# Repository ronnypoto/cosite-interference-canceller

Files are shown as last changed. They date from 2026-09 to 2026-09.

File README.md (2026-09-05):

# Active Wideband Co-Site Interference Cancellation System

**Tactical VHF, 30–88 MHz** · Final year project, B.Sc. Electrical Engineering
Afeka Tel Aviv Academic College of Engineering

**Ronny Pustilnik · Adir Lemair** — Advisor: Tzvika Rosenblum

---

## What this is

A real-time active canceller for co-site interference: the problem where a
high-power transmitter sitting next to a receiver saturates its input stages
and blinds it completely.

The system taps a reference copy of the interferer, multiplies it by two
adaptive weights (I and Q) in an analog vector modulator to synthesise an
anti-phase replica, and subtracts that replica in a 180° combiner. An STM32
closes the loop at 30 kHz using a logarithmic RF power detector as its only
feedback.

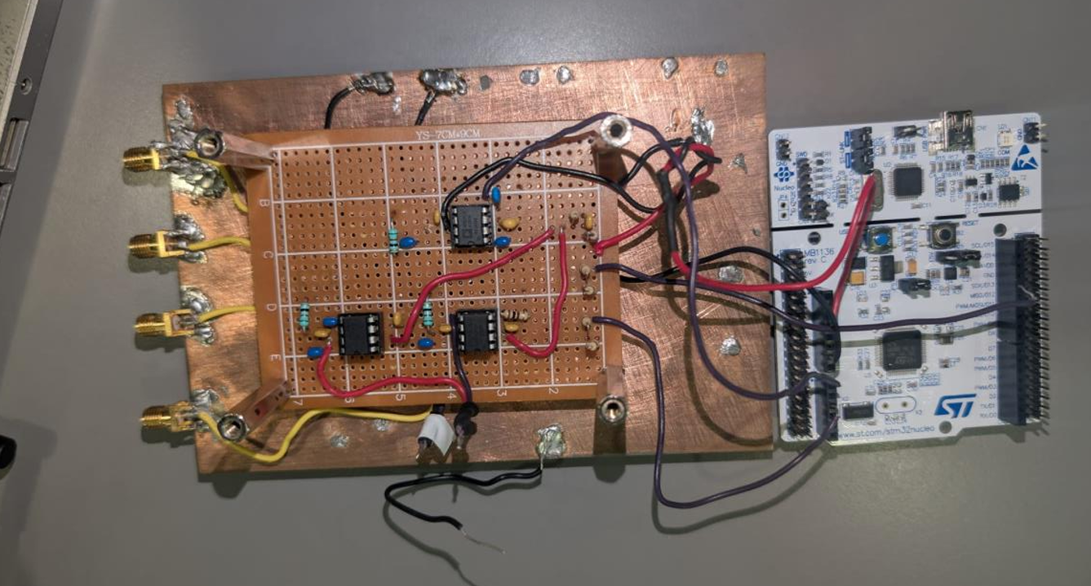
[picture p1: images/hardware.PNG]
The canceller board


## Measured results

| Metric | Target | Measured |
|---|---|---|
| Cancellation depth | ≥ 25 dB | **22.1 dB mean**, 28.6 dB peak, 13.6 dB worst across 30–88 MHz |
| Convergence, t(−15 dB) | < 10 ms | **1.9 ms mean**, 3.7 ms worst case |
| Desired-signal loss | ≤ 0.5 dB | **≤ 0.5 dB** down to 50 kHz separation |
| Combiner isolation ceiling | — | 21.1 dB (measured) |

Validated first as a MATLAB/Simulink digital twin, then built and measured in
hardware.

### Test 1 — across the band

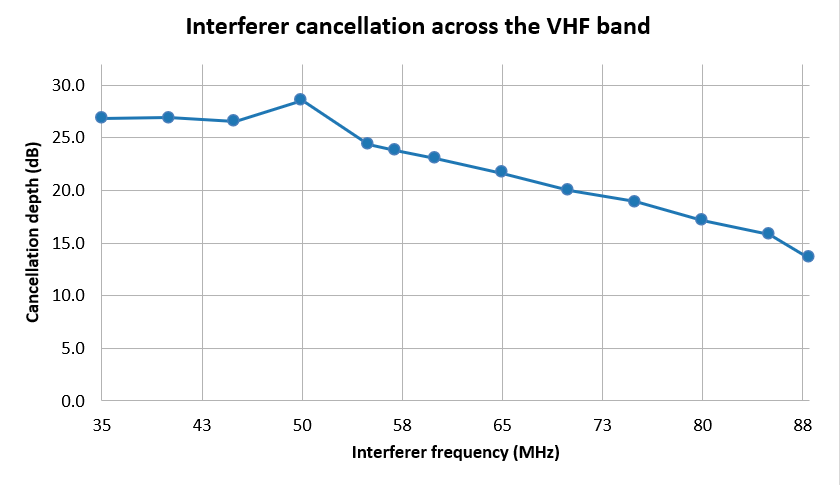
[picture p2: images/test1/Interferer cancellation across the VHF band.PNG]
Interferer cancellation across the VHF band


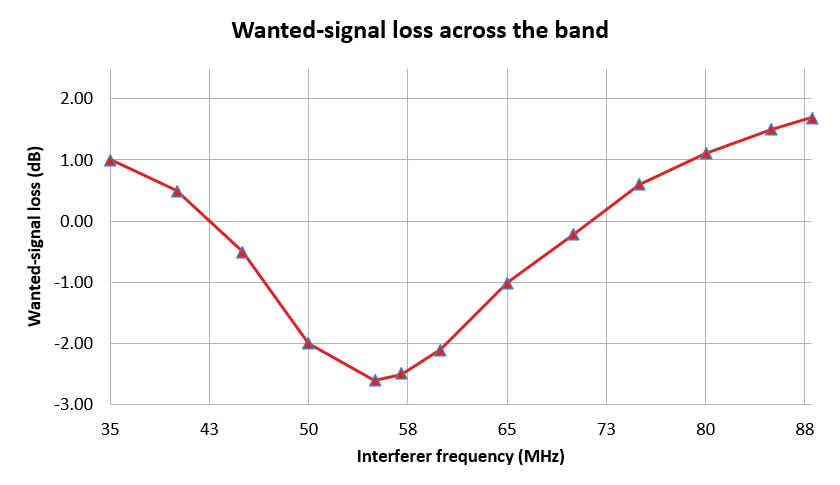
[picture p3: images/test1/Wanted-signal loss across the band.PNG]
Wanted-signal loss across the band


Depth peaks at 28.6 dB near 50 MHz and falls toward the band edges, where the
fixed λ/4 line no longer delivers 90°.

### Test 2 — frequency separation

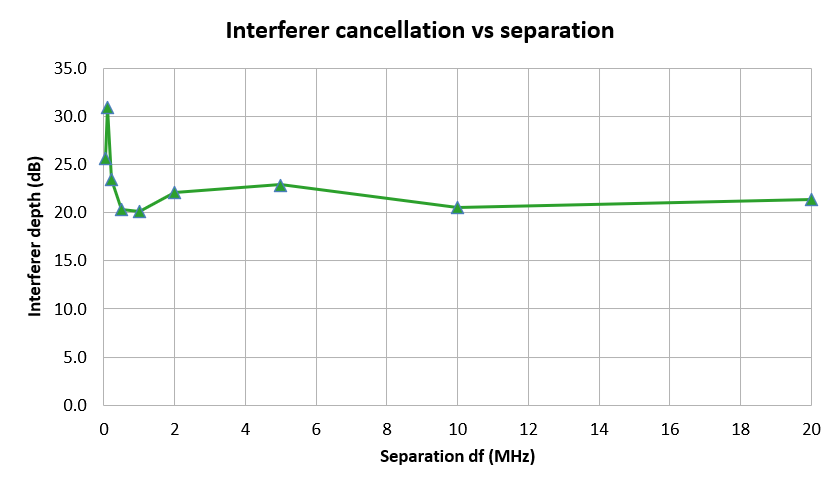
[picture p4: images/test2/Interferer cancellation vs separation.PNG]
Interferer cancellation vs separation


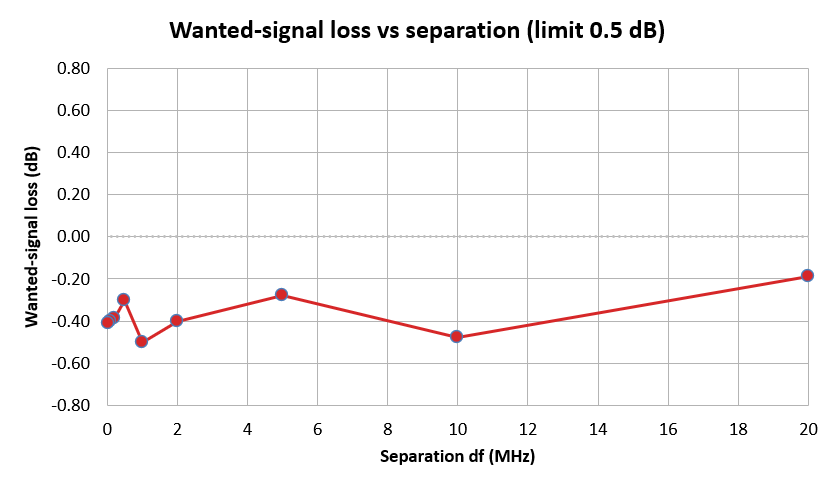
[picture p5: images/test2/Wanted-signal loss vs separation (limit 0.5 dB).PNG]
Wanted-signal loss vs separation


The wanted signal survives down to 50 kHz separation — a fractional bandwidth
of 0.00088, far beyond what any practical filter could resolve. This works
because cancellation is correlation-based, not frequency-based: the wanted
signal is absent from the reference, so no weight vector can cancel it.

### Test 3 — convergence

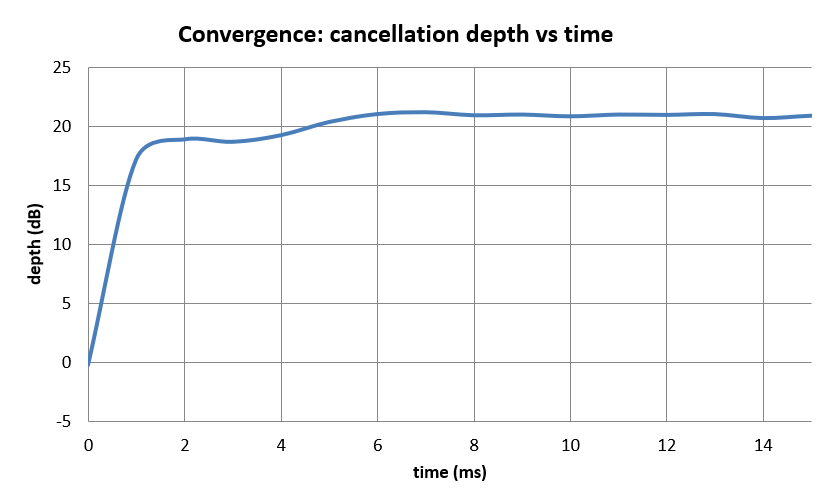
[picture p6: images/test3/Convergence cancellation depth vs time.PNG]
Convergence: cancellation depth vs time


Logged inside the MCU at 30 kHz with a 1200-sample buffer, so the spectrum
analyser's sweep time never enters the measurement.

---

## Where to look — key code

### The control algorithm

| What | File | Why it matters |
|---|---|---|
| **The search itself** | [`B_Firmware_Source/canceller.c`](B_Firmware_Source/canceller.c) §7 | 8-way pattern search with momentum. Comparison-based rather than gradient-based — this is the core design decision. |
| Adaptive averaging | [`canceller.c`](B_Firmware_Source/canceller.c) §4 | Averages 1→16 readings as the null deepens. √N SNR gain converts directly into deeper reachable nulls. |
| Scale-invariant step law | [`canceller.c`](B_Firmware_Source/canceller.c) §5 | `Step = 0.20 · 10^(depth_dB/20)` — needs no retuning when signal levels change. |
| Tunables and state | [`B_Firmware_Source/canceller.h`](B_Firmware_Source/canceller.h) | Every constant with the reasoning behind its value. |
| **Full design rationale** | [`B_Firmware_Source/CODE_WALKTHROUGH.md`](B_Firmware_Source/CODE_WALKTHROUGH.md) | Start here. Explains *why* each choice was made, including three real bugs and their root causes. |

### Hardware interface

| What | File | Why it matters |
|---|---|---|
| Control loop tick | [`B_Firmware_Source/main.c`](B_Firmware_Source/main.c) → `HAL_TIM_PeriodElapsedCallback` | The 30 kHz ISR: read ADC, step the algorithm, write both DACs. |
| Damaged-channel compensation | [`main.c`](B_Firmware_Source/main.c) → `dac1_fix()` | DAC1 was physically damaged mid-project (inverted output, reduced span). Compensated in software rather than rebuilt. |
| Weight → voltage mapping | [`canceller.c`](B_Firmware_Source/canceller.c) → `canc_weight_to_dac()` | Calibrated around the *measured* VREF (0.682 V), not the theoretical 0.825 V. |
| Grid scan + convergence logger | [`B_Firmware_Source/console.c`](B_Firmware_Source/console.c) | `k` sweeps the I/Q plane; `g` dumps a per-tick log with time-to-threshold analysis. |

### Simulation

| What | File |
|---|---|
| Algorithm as a Simulink block | [`C_Simulation/canceller_fcn_LP_V17b.m`](C_Simulation/canceller_fcn_LP_V17b.m) |
| Model initialisation | [`C_Simulation/init_project_10ms_fast.m`](C_Simulation/init_project_10ms_fast.m) |
| Depth vs frequency sweep | [`C_Simulation/sweep_cancellation_vs_frequency.m`](C_Simulation/sweep_cancellation_vs_frequency.m) |
| Two-tone / power-ratio study | [`C_Simulation/sweep_twotone_separation.m`](C_Simulation/sweep_twotone_separation.m) |
| Delay-mismatch tolerance | [`C_Simulation/sweep_delay_mismatch.m`](C_Simulation/sweep_delay_mismatch.m) |

---

## Key equations

**Replica synthesis** — two multipliers span the whole amplitude/phase plane:

```
replica(t) = I · ref(t) + Q · ref(t − τ)      τ = 4.39 ns  (λ/4 at 57 MHz)
```

Any amplitude and any phase can be produced from those two numbers, which is
why the search space is only 2-dimensional.

**dB-domain measurement** — the AD8307 is logarithmic, so the ADC reading is
*already* a dB measure. No `log()` is ever computed:

```
P_dB = adc_counts × DB_PER_COUNT
DB_PER_COUNT = 0.02994   (calibrated in situ against a spectrum analyser)
```

**Scale-invariant step size** — relative to the captured baseline, so the same
tuning works at −20 dBm or +10 dBm:

```
TargetStep = 0.20 × 10^(depth_dB / 20)
```

---

## Repository layout

```
A_Schematic/            KiCad schematic, netlist, PDF
B_Firmware_Source/      STM32 firmware (C) + full documentation
C_Simulation/           MATLAB / Simulink model and sweep scripts
D_Measurement_Results/  Raw laboratory measurements
images/                 Measurement plots and hardware photo
```

Component datasheets are not included here — they are available from the
manufacturers (Analog Devices, Mini-Circuits, STMicroelectronics).

---

## Hardware

- **Vector modulator:** 2 × AD835 four-quadrant analog multipliers
- **Detector:** AD8307 logarithmic power detector (~25 mV/dB)
- **MCU:** STM32F446RE (NUCLEO-F446RE), 30 kHz control loop
- **RF:** Mini-Circuits ZFSC-2-1W-S+ splitter, ZFSCJ-2-1-S+ 180° combiner,
  three hand-built resistive splitters
- **Construction:** RF prototyping on a copper ground plane

---

## Known limitations

**The detector is wideband.** The AD8307 measures *total* in-band power and
cannot separate the residual interferer from the desired signal. Once the
residual falls below the wanted tone, the loop goes blind — so closed-loop
depth is capped at roughly the interferer-to-signal power ratio.

This was predicted in simulation and then confirmed on hardware. It is the
single clearest direction for future work: a frequency-selective detector
(a coherent correlator against the existing reference, or a mixer with a
narrow IF filter) would remove the limit entirely.

**The delay line is fixed.** A single λ/4 coaxial section is cut for one
design frequency, so cancellation depth degrades toward the band edges — from
28.6 dB at 50 MHz down to 13.6 dB at 88 MHz. A true-time-delay element would
give wideband cancellation instead.

---

## License

Academic project submitted for a B.Sc. degree at Afeka Tel Aviv Academic
College of Engineering, 2026.

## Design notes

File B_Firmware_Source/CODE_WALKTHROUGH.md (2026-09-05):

# Firmware Walkthrough — Co-Site Interference Canceller

Firmware documentation for the co-site interference canceller.
This explains what each file does and *why* it is written that way.
Read alongside the source; SETUP.md covers the CubeIDE configuration.

**This document describes the FINAL firmware as submitted**, including the
in-situ calibrations and the workaround for the damaged DAC channel found
during laboratory testing (see report sections 10.2.5 and 9.5).

---

## The one-paragraph version

An interferer arrives on two paths. One path goes to the antenna/receiver
("main"), the other is tapped as a "reference". The board multiplies the
reference by two numbers, **I** and **Q**, to build a *replica* of the
interferer with adjustable amplitude and phase, then subtracts that replica
from the main path in a 180° combiner. What survives is measured by a log
detector. The MCU's only job is to keep hunting for the (I, Q) pair that makes
the surviving signal as small as possible.

```
        I                       Q
        |                       |
  ref --+--> AD835 #1 --> AD835 #2 --> replica --,
                                                  (-) 180° combiner --> residual
  main -------------------------------------(+)--'                        |
                                                                          v
                                                                   AD8307 detector
                                                                          |
                                                                     ADC (PA0)
                                                                          |
                                                              [ algorithm picks I,Q ]
                                                                          |
                                                            DAC (PA5 = I, PA4 = Q)
```

The maths the analog board implements is
`replica = I·ref + Q·(ref shifted 90°)`.
Any amplitude and phase can be produced from those two numbers — that is why
two multipliers are enough, and why the search space is only 2-dimensional.

---

## Files

| File | Role |
|---|---|
| `canceller.h` | State struct, tunables, API |
| `canceller.c` | The search algorithm (LP-V17b) |
| `console.h/.c` | Serial command interface, 115200 8N1 |
| `main.c` | HAL init + the two interrupt callbacks that glue it together |

---

## How the pieces connect at run time

Two things run concurrently:

**1. The 30 kHz control loop** — `HAL_TIM_PeriodElapsedCallback()` in `main.c`,
fired by TIM2 every 33.3 µs (PSC = 83, ARR = 32). Each tick it:
  - reads the ADC conversion started on the *previous* tick
  - starts the next conversion (never blocks waiting — 480-cycle sampling
    takes ~23 µs, which would eat a quarter of the tick if we waited)
  - if in AUTO, calls `canc_step()` to update I and Q
  - writes I and Q to the two DACs

**2. The main loop** — `console_poll()`, running as fast as it can. It handles
serial input/echo and telemetry. Nothing time-critical lives here.

The split matters: anything slow (UART transmit, `snprintf`) stays out of the
interrupt so the 33.3 µs control tick is never missed.

---

## `canceller.h` — the numbers worth understanding

```c
#define DWELL_LEN        1        /* ticks to wait after moving I/Q  */
#define DAC_LSB          0.0005f  /* smallest usable weight step     */
#define MARGIN_DB_BASE   0.15f    /* "is this actually better?" gate */
#define STARTUP_TICKS    30       /* settle before searching         */
#define AVG_MAX          16       /* cap on adaptive averaging       */
#define LOCK_AVG_MIN     2        /* averaging required before lock  */
#define TICK_MS          0.0333f  /* 30 kHz tick, for the g command  */
#define DB_PER_COUNT     0.029940f /* MEASURED, not theoretical      */
```

**`DWELL_LEN`** — after changing I or Q, the analog detector needs time to
settle before its reading means anything. The AD8307's output sees ~12.5 kΩ
into C1 = 1 nF, so τ ≈ 12.5 µs. At the 33.3 µs tick, one skipped tick is
already ~2.7τ, and the averaging that follows adds further settling time.
Judging a move on an unsettled reading turns the search into a random walk —
this was the actual bug in an earlier version (LP-V14), which dwelled in only
one of its two phases.

**`DB_PER_COUNT`** — the AD8307 is *logarithmic*, so the ADC reading is
already a dB measure of residual power. The whole algorithm therefore works
in dB and never needs a `log()`.

This constant was **calibrated in situ against the spectrum analyser** rather
than taken from the datasheet: stepping the generator down by exactly 10.0 dB
moved the ADC by 334 counts, giving 10.0/334 = **0.02994 dB per count**. That
corresponds to an AD8307 slope of ~26.9 mV/dB against the 25 mV/dB nominal —
within normal part-to-part variation. The theoretical value (0.032227) would
have over-reported every depth figure by 7.6%.

**`MARGIN_DB_BASE`** — a move only counts as an improvement if the power drops
by more than this. It has to exceed the measurement noise or every comparison
is a coin flip. 0.15 dB ≈ 5 ADC counts.

---

## `canceller.c` — the algorithm, step by step

### Weight → voltage mapping

```c
uint16_t canc_weight_to_dac(float w)   /* w in [-1,+1] -> 0..4095 */
```

I and Q live in [−1, +1]. The DAC outputs 0–3.3 V, which passes through a
10k/10k divider (so Y1 = DAC/2) and is compared against VREF on the AD835's
Y2 pin. The multiplier acts on `(Y1 − Y2)`.

**VREF was measured at 0.682 V, not the 0.825 V the divider predicts.** The
30k/10k divider has a 7.5 kΩ Thevenin impedance and the two AD835 Y-inputs
draw bias current, dropping ~143 mV. `canc_weight_to_dac()` is calibrated
around the *measured* value, so w = 0 is a true zero weight:

| w | DAC | Y1 | Y1−Y2 | meaning |
|---|---|---|---|---|
| −1 | 0 V | 0 V | −0.682 V | full negative (180° flip) |
| 0 | 1.364 V | 0.682 V | **0 V** | zero output |
| +1 | 2.728 V | 1.364 V | +0.682 V | full positive |

**This is why Y2 must go to VREF and never to ground.** With Y2 grounded,
`Y1 − Y2` can never go negative, the multiplier loses its sign, and half the
I/Q plane becomes unreachable — so most nulls simply cannot be formed.

### The tick, in order

**1. Startup (`WaitTimer < 30`)**
Do nothing but watch. Records `InitP_dB` = the *uncancelled* power level.
Everything afterwards is measured relative to this, which makes the algorithm
scale-invariant: it behaves the same whether the interferer is at −20 dBm or
+10 dBm.

**2. Locked** — if the search has converged, hold the best point and return.

**3. Dwell** — if we just moved, skip this tick. (See `DWELL_LEN` above.)

**4. Adaptive integration** — the clever part:

```c
depth_dB = P - InitP_dB;          /* how far down we are */
if      (depth_dB > -13) AvgTarget = 1;
else if (depth_dB > -20) AvgTarget = 2;
...
else                     AvgTarget = 16;
```

Far from the null, one reading is enough — move fast. Near the null the
residual approaches the noise floor and single readings become unreliable, so
we average up to 16. Averaging N samples improves SNR by √N, so 16 readings
buy ~12 dB of extra usable measurement range — which converts directly into a
deeper reachable null. Speed where speed is free, precision where it matters.

**5. Step-size law**

```c
TargetStep = 0.20f * powf(10.0f, depth_dB / 20.0f);
```

Step size shrinks with the square root of the remaining power. Big strides at
first, fine steps near the bottom — and because it is relative to `InitP_dB`,
it needs no retuning when signal levels change.

**6. Adaptive margin**

```c
margin_dB = MARGIN_DB_BASE / sqrtf(AvgTarget);
```

More averaging → quieter measurement → smaller improvements can be trusted.

**7. The 8-way pattern search** — the core:

```c
if (P < LastP_dB - margin_dB) {   /* better! */
```
- **Improvement** → keep the position, save it as best, and *grow* the step
  (doubling on a 2-win streak — "momentum", so long runs downhill take
  log(distance) decisions instead of linear).
- **Failure** → undo the step, rotate to the next of 8 directions
  (±I, ±Q, and the four diagonals). After all 8 fail, return to the best known
  point and halve the step.

Why "better or worse?" instead of computing a gradient: it only needs a
*comparison*, so it tolerates noise well. A gradient method divides small
differences of noisy readings and amplifies that noise — we tried it (V16,
V18) and it lost every time. V18 in particular diverged on hardware.

**Two phases:** phase 1 is coarse (large steps, capped at 0.25); once 6 dB of
cancellation is achieved it switches to phase 2, fine (capped at 0.04). The
"anti-stagnation kick" in phase 2 re-expands the step once if the search
stalls, to escape a shallow local minimum.

**Lock** happens only after a long stall, at the DAC quantisation floor, with
averaging active — three conditions, so it cannot latch early by luck.

One bug worth recording: the lock gate originally required
`AvgTarget >= AVG_MAX` (16), which the adaptive-averaging ladder only reaches
past 33 dB of depth. Real achievable depth on this detector is ~20 dB, so the
condition was **mathematically unreachable** and every run ended "never locked
within the window" no matter how well it had converged. `LOCK_AVG_MIN = 2` is
the reachable gate.

### The hop detector (in `main.c`'s AUTO path via `canc_init`)

An earlier version reset the search whenever `Error_Power > 100` — an
*absolute* threshold. Change the signal level and it latches on forever,
resetting every tick, output stuck at zero. The current version compares
against `InitP_dB` (scale-invariant) and requires the jump to be *sustained*,
so a single noise spike cannot trigger it.

---

## The damaged DAC channel — `dac1_fix()`

```c
static uint16_t dac1_fix(float w)
{
    float v = 1.21f - w * 1.35f;      /* inverted, over-driven */
    ...
}
```

Measured behaviour of PA4 after the fault: w = −1 → 2.06 V, w = 0 → 1.21 V,
w = +1 → 0.36 V. Two defects at once — the output runs **backwards**, and its
span is **1.7 V instead of 2.7 V**.

`dac1_fix()` corrects both: the negative coefficient undoes the inversion, and
the 1.35 magnitude over-drives the request to recover most of the lost span.
After compensation the axis reaches roughly ±0.59 in weight instead of ±1.0.

This is the reason the ISR looks asymmetric:

```c
HAL_DAC_SetValue(&hdac, DAC_CHANNEL_2, DAC_ALIGN_12B_R,
                 canc_weight_to_dac(g_canc.I));   /* PA5 - healthy   */
HAL_DAC_SetValue(&hdac, DAC_CHANNEL_1, DAC_ALIGN_12B_R,
                 dac1_fix(g_canc.Q));             /* PA4 - damaged   */
```

## `console.c` — the interface

| Command | Effect |
|---|---|
| `m` | manual mode |
| `a` | auto mode — resets the search, closes the loop, arms the logger |
| `i0.5` | set I = 0.5 |
| `q-0.3` | set Q = −0.3 |
| `z` | zero both weights (the baseline state) |
| `b` | capture baseline ADC at I = Q = 0 |
| `k` | automatic grid scan — coarse, fine, ultra-fine |
| `g` | dump convergence log with time-to-threshold analysis |
| `v` | raw ADC + depth vs baseline |
| `t` | toggle telemetry streaming |
| `s` | status |

**`k` — the grid scan.** Three passes over the I/Q plane: coarse 9×9, then
fine ±0.25 in 0.05 steps, then ultra-fine in 0.01 steps. Each point is
measured with `MEAS_AVG = 16` averaged readings because the raw ADC wanders
1.3–2.3 dB at a *fixed* I/Q — with only 4 averages the scan was ranking
points on noise rather than signal.

**`g` — the convergence logger.** `canc_step()` records the raw ADC on every
tick into a 1200-sample RAM buffer (40 ms at 30 kHz), before any early return,
so the time axis is exact. `g` then reports the time to reach −3, −6, −10,
−15, −20, −25 and −30 dB, the lock time, and a CSV decimated to one line per
millisecond. This is what produced the convergence figures in the report —
the analyser's sweep time is irrelevant because the measurement happens
inside the MCU.

Two implementation details worth noting:

**Echo is queued, not transmitted in the ISR.** `console_on_rx_byte()` runs in
the UART interrupt and only pushes characters into a ring buffer;
`console_poll()` drains it from the main loop. A blocking UART transmit inside
an interrupt would be ~87 µs per byte at 115200 — nearly a whole control tick.

**It boots in MANUAL.** Nothing moves until someone types `a`. Deliberate: you
never want an adaptive loop driving RF hardware the instant power is applied.

---

## Things that will bite you

1. **Y2 to ground instead of VREF** — kills the phase flip. Has been
   reintroduced repeatedly by well-meaning edits.
2. **Y1 without its 10 k series resistor** — puts 0–3.3 V on a ±1 V input.
3. **W1 → Z2 must be a direct wire** — Z is a unity-gain summing input; any
   divider there leaves I weaker than Q and the plane becomes skewed.
4. **Keep `clamp_iq()` and the `k` scan bounds in agreement.** The search in
   `canc_step()` and the grid scan in `console.c` must explore the *same*
   reachable box. At one point the clamp restricted Q to ±0.59 while the scan
   still swept ±1.0, so `k` kept finding nulls that `a` could never reach —
   which looked like an algorithm failure but was purely a bounds mismatch.
5. **The detector is wideband.** It measures *total* power and cannot tell the
   wanted signal from the interferer residual. So cancellation stalls at
   roughly the interferer-to-wanted power ratio: a wanted tone 10 dB below the
   interferer floors you at ~10 dB, no matter how good the hardware is. This
   is a measured, reproduced result — not a bug — and it is what motivates
   selective (frequency-aware) detection as future work.
6. **ADC sampling time must be 480 cycles.** The AD8307's ~12.5 kΩ output
   cannot charge the sample-and-hold in a short window; shorter settings give
   readings that look plausible and are wrong.
7. **DAC1 (PA4) is physically damaged** on this board — output inverted, span
   reduced to ~1.7 V. A short on the Nucleo header during assembly caused it.
   The channels were swapped in firmware: I drives PA5 (healthy DAC2), Q drives
   PA4 through `dac1_fix()`. On an undamaged board, delete `dac1_fix()` and use
   `canc_weight_to_dac()` for both channels — then Q regains its full ±1.0
   range and `clamp_iq()` should be widened to match.
8. **PA5 is also wired to the Nucleo's LD2 LED**, which loads the output very
   slightly. It mattered more when PA5 carried Q; on the final build it carries
   I and the effect is negligible.

---

## Suggested reading order

1. This document
2. `canceller.h` — the state struct tells you what the algorithm remembers
3. `canceller.c` §7, the pattern search — the heart of it
4. `main.c`, `HAL_TIM_PeriodElapsedCallback` — how a tick actually flows
5. `main.c`, `dac1_fix()` — why the two channels are handled differently
6. `console.c` — the scan and the convergence logger

---

## Measured performance (final build)

| Metric | Result |
|---|---|
| Cancellation depth | 22.1 dB mean, 28.6 dB best, 13.6 dB worst across 30–88 MHz |
| Convergence, t(−15 dB) | 1.9 ms mean, 3.7 ms worst — target was 10 ms |
| Wanted-signal loss | ≤0.5 dB down to 50 kHz separation |
| Detector calibration | 0.02994 dB/count, verified against the analyser |

The detector-measured depth reads a few dB lower than the analyser because the
AD8307 is wideband and saturates on the wanted tone once the interferer
residual falls below it. That gap is a measured result, not an error — see
report section 10.2.6.

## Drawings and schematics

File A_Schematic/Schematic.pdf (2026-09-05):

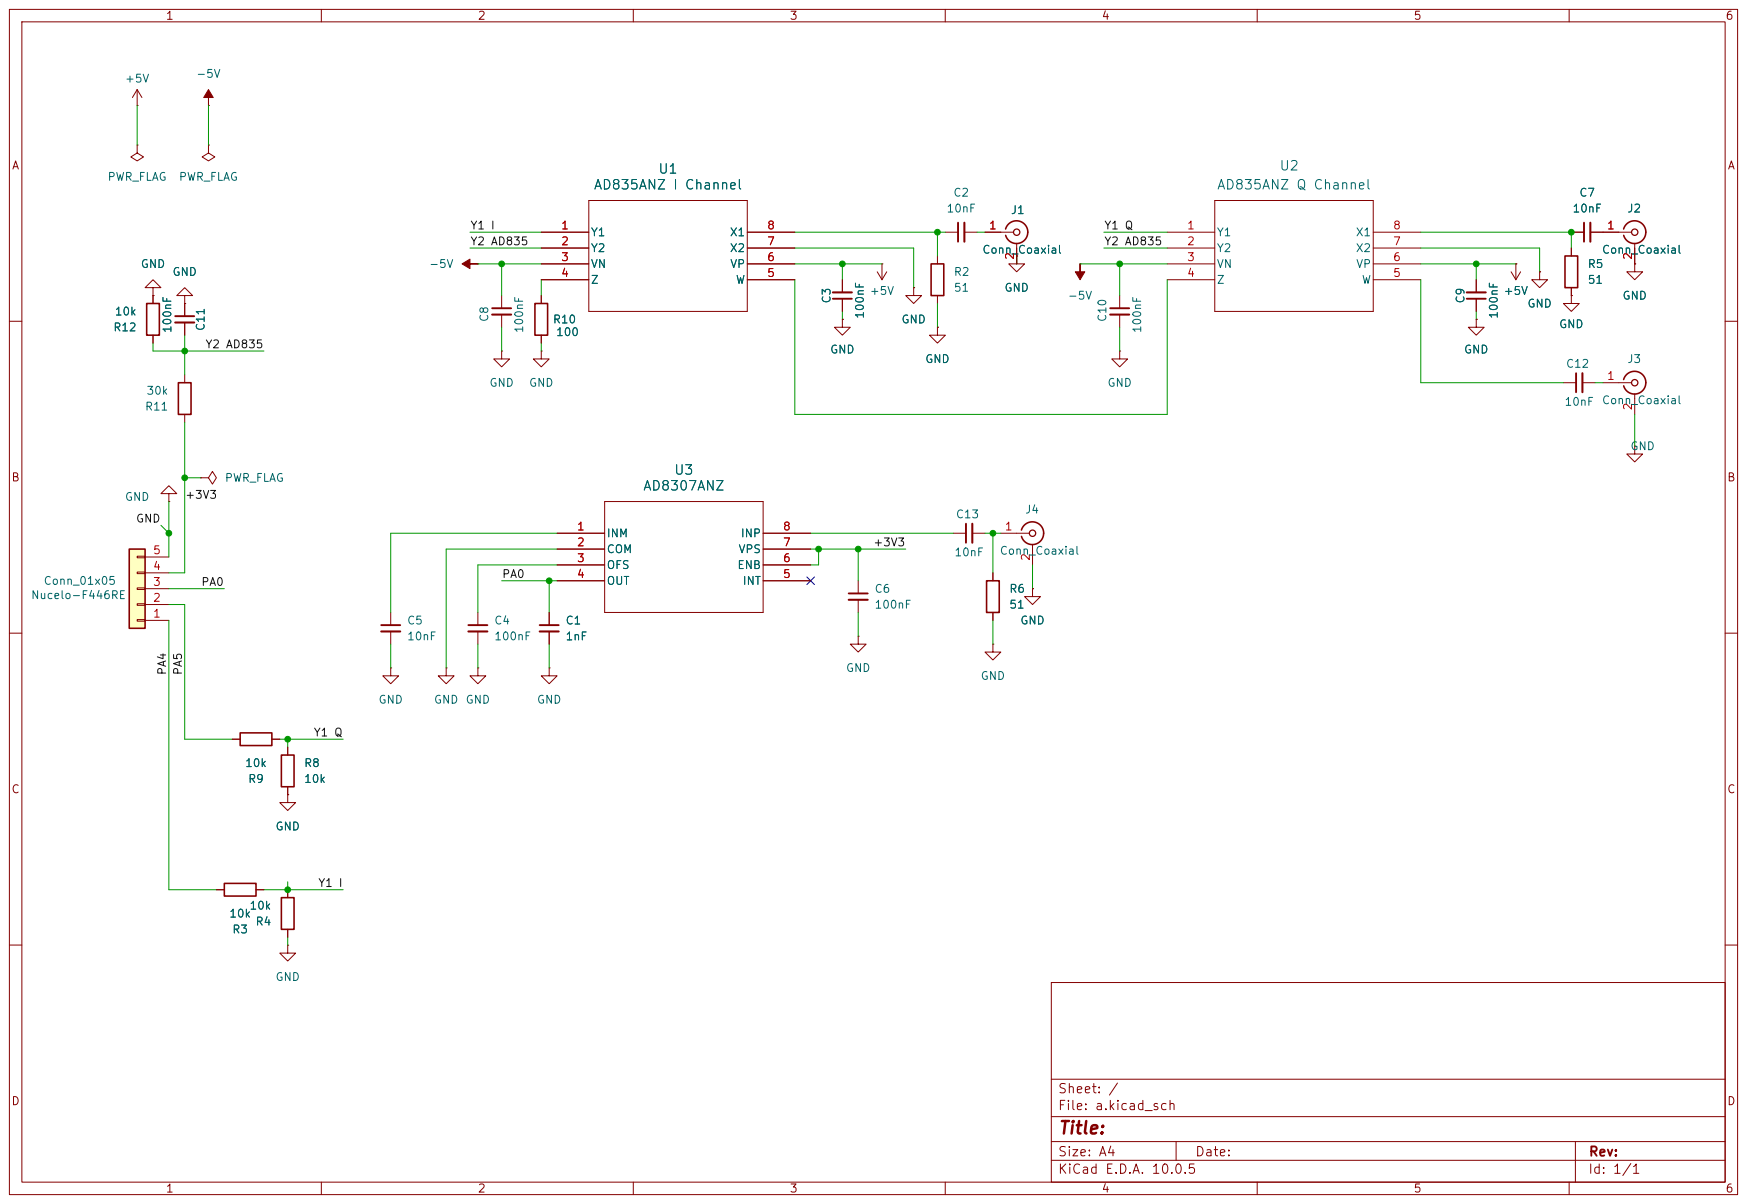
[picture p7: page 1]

Size: A4 | Rev:
KiCad E.D.A. 10.0.5 | Id: 1/1

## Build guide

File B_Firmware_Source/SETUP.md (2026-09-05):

# STM32CubeIDE Setup — Co-Site Canceller (NUCLEO-F446RE)

## 0. Pin map

| Signal | Pin | Peripheral |
|---|---|---|
| AD8307 OUT (detector) | **PA0** | ADC1_IN0 |
| I control → AD835 #1 Y1 | **PA4** | DAC_OUT1 |
| Q control → AD835 #2 Y1 | **PA5** | DAC_OUT2 |
| Console TX/RX | PA2 / PA3 | USART2 (ST-Link VCP) |
| +3V3 / GND | 3V3 / GND | to your board header |

---

## 1. Create the project

1. **File → New → STM32 Project**
2. **Board Selector** tab → search `NUCLEO-F446RE` → select it → **Next**
3. Name it `canceller` → **Finish**
4. When asked *"Initialize all peripherals with their default Mode?"* → **Yes**
   (this wires up USART2 to the ST-Link VCP for you)

---

## 2. Clock configuration

**Clock Configuration** tab:
- Set **HCLK = 84 MHz** (type 84 into the HCLK box and press Enter; let it auto-solve)
- This gives APB1 = 42 MHz, and **APB1 Timer clocks = 84 MHz**

> If you use a different HCLK, you must recompute the TIM2 prescaler in step 3.

---

## 3. Peripheral configuration (Pinout & Configuration tab)

### ADC1 — detector input
- **Analog → ADC1** → tick **IN0**
- Parameter Settings:
  - Resolution: **12 bits**
  - Continuous Conversion Mode: **Disabled**
  - External Trigger Conversion Source: **Regular Conversion launched by software**
  - **Rank → Sampling Time: `480 Cycles`**  ← **important**

> The AD8307 output has ~12.5 kΩ source impedance. Short sampling times will
> not let the ADC sample-and-hold settle and the readings will be wrong.
> 480 cycles is the safe choice.

### DAC — I and Q outputs
- **Analog → DAC** → tick **OUT1** and **OUT2**
- For both channels:
  - Output Buffer: **Enable**
  - Trigger: **None**

### TIM2 — 10 kHz control loop
- **Timers → TIM2** → Clock Source: **Internal Clock**
- Parameter Settings:
  - Prescaler: **83**
  - Counter Period (ARR): **99**
  - → 84 MHz / 84 / 100 = **10 kHz**
- **NVIC Settings** tab → tick **TIM2 global interrupt**

### USART2 — console
- Already enabled by the board defaults. Confirm:
  - Mode: **Asynchronous**
  - Baud: **115200**, 8 bits, no parity, 1 stop bit
- **NVIC Settings** → tick **USART2 global interrupt**

Then **Ctrl+S** to save and generate code.

---

## 4. Add the source files

1. Copy `canceller.h` and `console.h` into `Core/Inc/`
2. Copy `canceller.c` and `console.c` into `Core/Src/`
3. Right-click the project → **Refresh** (F5)

---

## 5. Edit `main.c`

Paste each block into the matching `USER CODE` section.

### `/* USER CODE BEGIN Includes */`
```c
#include "canceller.h"
#include "console.h"
```

### `/* USER CODE BEGIN PV */`
```c
canc_state_t  g_canc;
canc_mode_t   g_mode = MODE_MANUAL;
static uint8_t g_rx_byte;
volatile uint16_t g_adc_latest = 0;
```

### `/* USER CODE BEGIN 2 */`  (after all the MX_*_Init calls)
```c
  canc_init(&g_canc);
  g_mode = MODE_MANUAL;              /* boot safe: nothing moves until 'a' */

  HAL_DAC_Start(&hdac, DAC_CHANNEL_1);
  HAL_DAC_Start(&hdac, DAC_CHANNEL_2);
  HAL_DAC_SetValue(&hdac, DAC_CHANNEL_1, DAC_ALIGN_12B_R, 2048);
  HAL_DAC_SetValue(&hdac, DAC_CHANNEL_2, DAC_ALIGN_12B_R, 2048);

  HAL_UART_Receive_IT(&huart2, &g_rx_byte, 1);
  console_init();

  HAL_ADC_Start(&hadc1);             /* first conversion; ISR reads it */
  HAL_TIM_Base_Start_IT(&htim2);
```

### `/* USER CODE BEGIN WHILE */` (inside the `while (1)` loop)
```c
    console_poll(&g_canc, &g_mode);
```

### `/* USER CODE BEGIN 4 */`
```c
/* 10 kHz control loop */
void HAL_TIM_PeriodElapsedCallback(TIM_HandleTypeDef *htim)
{
  if (htim->Instance != TIM2) return;

  /* read the conversion started last tick, then start the next one.
     480-cycle sampling ~ 23 us, well inside the 100 us tick. */
  if (HAL_ADC_PollForConversion(&hadc1, 0) == HAL_OK) {
      g_adc_latest = (uint16_t)HAL_ADC_GetValue(&hadc1);
  }
  HAL_ADC_Start(&hadc1);

  if (g_mode == MODE_AUTO) {
      canc_step(&g_canc, g_adc_latest);
  } else {
      g_canc.last_adc = g_adc_latest;   /* keep 'v' live in manual mode */
  }

  HAL_DAC_SetValue(&hdac, DAC_CHANNEL_1, DAC_ALIGN_12B_R,
                   canc_weight_to_dac(g_canc.I));
  HAL_DAC_SetValue(&hdac, DAC_CHANNEL_2, DAC_ALIGN_12B_R,
                   canc_weight_to_dac(g_canc.Q));
}

/* console RX */
void HAL_UART_RxCpltCallback(UART_HandleTypeDef *huart)
{
  if (huart->Instance == USART2) {
      console_on_rx_byte(g_rx_byte);
      HAL_UART_Receive_IT(&huart2, &g_rx_byte, 1);
  }
}
```

---

## 6. Enable float printf

`snprintf("%f")` returns nothing useful unless you enable it:

**Project → Properties → C/C++ Build → Settings → MCU/MPU Settings**
→ tick **Use float with printf from newlib-nano**

Then **Project → Clean**, then **Build**.

---

## 7. Flash and open the console

1. USB cable to the Nucleo's ST-Link port
2. **Run → Debug** (or the hammer, then the green Run arrow)
3. Open a terminal (PuTTY / TeraTerm) on the **STMicroelectronics STLink Virtual COM Port**
   - 115200, 8N1, no flow control
4. Press Enter — you should see the `>` prompt. Type `h` for help.

---

## 8. Bench bring-up (no RF yet)

Do these **in order**. Each is a gate.

### 8.1 Rails, sockets EMPTY
- Ch1 **+**→+5V, Ch1 **−**→GND
- Ch2 **+**→**GND**, Ch2 **−**→−5V ← reversed kills both AD835s
- Current limit **100 mA**
- Nucleo on USB (gives +3V3)
- Meter: **+5.00 / −5.00 / +3.3 / VREF ≈ 0.825 V**

### 8.2 Insert chips
Pin 1 to the notch. Re-check the rails.

### 8.3 Control interface test
At the console, in MANUAL mode, measure **Y1−Y2** at each AD835:

| Command | Expected Y1−Y2 |
|---|---|
| `i0` | 0.000 V |
| `i1` | +0.825 V |
| `i-1` | −0.825 V |
| `q0` / `q1` / `q-1` | same on AD835 #2 |

This proves DAC → divider → chip. **If this fails, stop and fix it before RF.**

### 8.4 Detector path
- `v` with no RF → some low baseline count
- Inject a known level into SMA4 (through the attenuator!) → `v` should rise
- Two known levels give you the slope: should be ~**25 mV/dB** (≈0.78 counts/dB… i.e. ~31 counts per dB is wrong — expect **~0.032 dB per count**, so ~31 counts per dB)

### 8.5 Manual null (the milestone)
- Jammer on, wanted generator **off**
- Hand-tune with `i` / `q` while watching the analyser
- **≥15 dB by hand = hardware proven.** Photograph it.
- If it will not null by hand → **STOP**, debug RF. Do not close the loop.

### 8.6 Close the loop
- Type `a`. Watch the analyser and use `t` to stream telemetry.
- Record depth and time-to-lock.
- `s` shows phase, step size, and whether it has LOCKED.

---

## 9. Two gotchas specific to this board

**PA5 is also the user LED (LD2).** On a NUCLEO-64 the green LED sits on PA5,
which is your Q DAC output. The LED plus its series resistor load the DAC and
will clamp/distort the top of the Q range (above the LED's forward voltage).
Check it: set `q1` and see whether LD2 lights. If it does and your Q range
looks compressed at the top, remove the LD2 solder bridge / series resistor,
or keep Q operation in the lower part of the range. The I channel (PA4) is
unaffected.

**VDDA must be the same 3V3 that feeds your VREF divider.** The DAC reference
is VDDA. If your divider is fed from a different 3.3 V source, the null point
drifts. Take pin 4 of your header from the Nucleo's own 3V3 pin.

---

## 10. Command reference

| Cmd | Action |
|---|---|
| `m` | manual mode |
| `a` | auto mode — resets the search and closes the loop |
| `i0.5` | set I = 0.5 |
| `q-0.3` | set Q = −0.3 |
| `v` | raw ADC (detector calibration) |
| `t` | toggle telemetry streaming |
| `s` | status |
| `h` | help |

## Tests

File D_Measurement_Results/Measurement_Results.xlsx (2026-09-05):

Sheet: README
Co-Site Canceller - Advisor Test Programme
Ronny Pustilnik / Adir Lemaer - Afeka - 30-88 MHz VHF
THE THREE REQUESTED TESTS
1. Cancellation across the whole 30-88 MHz band, in 5 MHz steps | -> sheet T1_BandSweep
2. How close in frequency the interferer may be before the wanted | -> sheet T2_Separation
signal is degraded by more than 0.5 dB
3. Convergence time of the algorithm | -> sheet T3_Convergence
HOW TO USE
Type only in YELLOW cells. Grey cells are formulas.
Grey italic rows are examples - delete them before submitting.
BASELINE DEFINITION - important
The uncancelled reference is the 'z' state (I = Q = 0, true zero weight
after the VREF calibration). This was verified against a physically
disconnected replica: z reads within ~1 dB of the disconnected case,
so z is a valid baseline and is far quicker to use at every point.
MEASURING FROM THE ANALYSER
Set the marker to the tone frequency MANUALLY every time.
Do NOT use Peak Search - once the interferer drops below the wanted
tone it will jump to the wrong peak and the numbers become nonsense.
Span 500 kHz, RBW 30 kHz, VBW 30 kHz keeps the sweep near 100 ms.
Fix the attenuation at 20 dB for the whole session.
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

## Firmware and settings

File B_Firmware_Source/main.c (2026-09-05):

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
/* Includes ------------------------------------------------------------------*/
#include "main.h"

/* USER CODE BEGIN Includes */
#include "canceller.h"
#include "console.h"
/* USER CODE END Includes */

ADC_HandleTypeDef hadc1;

DAC_HandleTypeDef hdac;

TIM_HandleTypeDef htim2;

UART_HandleTypeDef huart2;

/* USER CODE BEGIN PV */
canc_state_t  g_canc;
canc_mode_t   g_mode = MODE_MANUAL;
volatile uint16_t g_adc_latest = 0;
static uint8_t g_rx_byte;
/* USER CODE END PV */

void SystemClock_Config(void);
static void MX_GPIO_Init(void);
static void MX_USART2_UART_Init(void);
static void MX_ADC1_Init(void);
static void MX_DAC_Init(void);
static void MX_TIM2_Init(void);
/* USER CODE BEGIN PFP */
static uint16_t dac1_fix(float w);
/* USER CODE END PFP */

/**
  * @brief  The application entry point.
  * @retval int
  */
int main(void)
{

  /* MCU Configuration--------------------------------------------------------*/

  /* Reset of all peripherals, Initializes the Flash interface and the Systick. */
  HAL_Init();

  /* Configure the system clock */
  SystemClock_Config();

  /* Initialize all configured peripherals */
  MX_GPIO_Init();
  MX_USART2_UART_Init();
  MX_ADC1_Init();
  MX_DAC_Init();
  MX_TIM2_Init();
  /* USER CODE BEGIN 2 */
   canc_init(&g_canc);
   g_mode = MODE_MANUAL;

   HAL_DAC_Start(&hdac, DAC_CHANNEL_1);
   HAL_DAC_Start(&hdac, DAC_CHANNEL_2);

   /* Set initial neutral points */
   HAL_DAC_SetValue(&hdac, DAC_CHANNEL_1, DAC_ALIGN_12B_R, dac1_fix(0.0f));
   HAL_DAC_SetValue(&hdac, DAC_CHANNEL_2, DAC_ALIGN_12B_R, canc_weight_to_dac(0.0f));

   console_init();
   HAL_UART_Receive_IT(&huart2, &g_rx_byte, 1);

   HAL_ADC_Start(&hadc1);
   HAL_TIM_Base_Start_IT(&htim2);
   /* USER CODE END 2 */

  /* Infinite loop */
  /* USER CODE BEGIN WHILE */
  while (1)
  {
      console_poll(&g_canc, &g_mode);
    /* USER CODE END WHILE */

    /* USER CODE BEGIN 3 */
  }
  /* USER CODE END 3 */
}

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
/* USER CODE BEGIN 4 */
/* DAC1 (PA4) damaged: output inverted with reduced span.
 * Measured: w=-1 -> 2.06 V, w=0 -> 1.21 V, w=+1 -> 0.36 V
 * Span 1.70 V vs 2.70 V healthy -> this axis reaches only ~+/-0.43. */
static uint16_t dac1_fix(float w)
{
    if (w >  1.0f) w =  1.0f;
    if (w < -1.0f) w = -1.0f;
    float v = 1.21f - w * 1.35f;
    int32_t code = (int32_t)(v / 3.3f * 4095.0f + 0.5f);
    if (code < 0)    code = 0;
    if (code > 4095) code = 4095;
    return (uint16_t)code;
}
void HAL_TIM_PeriodElapsedCallback(TIM_HandleTypeDef *htim)
{
    if (htim->Instance != TIM2) return;

    if (HAL_ADC_PollForConversion(&hadc1, 0) == HAL_OK) {
        g_adc_latest = (uint16_t)HAL_ADC_GetValue(&hadc1);
    }
    HAL_ADC_Start(&hadc1);

    if (g_mode == MODE_AUTO) {
        canc_step(&g_canc, g_adc_latest);
    } else {
        g_canc.last_adc = g_adc_latest;
    }
    HAL_DAC_SetValue(&hdac, DAC_CHANNEL_2, DAC_ALIGN_12B_R,
                     canc_weight_to_dac(g_canc.I));   /* PA5 - healthy */
    HAL_DAC_SetValue(&hdac, DAC_CHANNEL_1, DAC_ALIGN_12B_R,
                     dac1_fix(g_canc.Q));             /* PA4 - compensated */
}

void HAL_UART_RxCpltCallback(UART_HandleTypeDef *huart)
{
    if (huart->Instance == USART2) {
        console_on_rx_byte(g_rx_byte);
        HAL_UART_Receive_IT(&huart2, &g_rx_byte, 1);
    }
}

void HAL_UART_ErrorCallback(UART_HandleTypeDef *huart)
{
    if (huart->Instance == USART2) {
        // Clear error flags and re-enable interrupt reception
        __HAL_UART_CLEAR_OREFLAG(huart);
        __HAL_UART_CLEAR_NEFLAG(huart);
        __HAL_UART_CLEAR_FEFLAG(huart);
        HAL_UART_Receive_IT(&huart2, &g_rx_byte, 1);
    }
}
/* USER CODE END 4 */
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


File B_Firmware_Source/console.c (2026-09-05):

/* console.c - serial console for the co-site canceller
 * USART2 @ 115200 8N1, routed to the ST-Link virtual COM port.
 *
 * v2: adds LOCAL ECHO. Without it the terminal shows nothing while you
 * type, which is indistinguishable from a dead RX path. Characters are
 * queued in the RX interrupt and echoed from console_poll() in the main
 * loop, so no blocking UART transmit ever happens inside an ISR.
 */

#include "console.h"
#include "main.h"
#include <stdio.h>
#include <string.h>
#include <stdlib.h>

extern UART_HandleTypeDef huart2;

#define RXBUF_LEN   32
#define ECHO_LEN    64      /* must be a power of two */

static volatile char     rxbuf[RXBUF_LEN];
static volatile uint8_t  rxlen  = 0;
static volatile bool     rxdone = false;

/* echo ring buffer, filled in the ISR, drained in the main loop */
static volatile uint8_t  echo_buf[ECHO_LEN];
static volatile uint16_t echo_head = 0;   /* write index (ISR)  */
static volatile uint16_t echo_tail = 0;   /* read index  (main) */

static bool              telemetry = false;
static uint32_t          telem_last = 0;

void console_print(const char *msg)
{
    HAL_UART_Transmit(&huart2, (uint8_t *)msg, strlen(msg), 100);
}

static void echo_push(uint8_t c)
{
    uint16_t next = (uint16_t)((echo_head + 1u) & (ECHO_LEN - 1u));
    if (next != echo_tail) {          /* drop if full, never block */
        echo_buf[echo_head] = c;
        echo_head = next;
    }
}

static void echo_drain(void)
{
    while (echo_tail != echo_head) {
        uint8_t c = echo_buf[echo_tail];
        echo_tail = (uint16_t)((echo_tail + 1u) & (ECHO_LEN - 1u));
        HAL_UART_Transmit(&huart2, &c, 1, 10);
    }
}

/* ---------------------------------------------------------------------
 * Baseline + automatic grid scan
 *
 * The TIM2 ISR keeps writing s->I / s->Q to the DACs and refreshing
 * s->last_adc every 100 us, so a scan can simply set a weight, wait, and
 * read back. Blocking with HAL_Delay here is safe: the control loop lives
 * in the interrupt, not in this loop.
 * ------------------------------------------------------------------- */

static uint16_t base_adc  = 0;      /* uncancelled reference reading */
static bool     base_valid = false;

/* Settle, then average MANY readings.
 *
 * The raw ADC was measured to wander 1.3-2.3 dB (40-70 counts) at a FIXED
 * I/Q. Averaging only 4 readings left ~0.6-1.1 dB of uncertainty - larger
 * than many of the differences the scan needs to resolve between candidate
 * points, so comparisons were partly noise-driven. 16 readings cut that by
 * sqrt(16)=4x, to ~0.15-0.3 dB. Cost: ~18 ms/point instead of 6 ms - the
 * full 3-stage scan takes ~15 s instead of ~2 s. Worth it for a reliable
 * result. */
#define MEAS_AVG   16

static uint16_t measure_point(canc_state_t *s)
{
    uint32_t acc = 0;
    HAL_Delay(2);                    /* settle */
    for (int k = 0; k < MEAS_AVG; k++) {
        acc += s->last_adc;
        HAL_Delay(1);
    }
    return (uint16_t)(acc / (uint32_t)MEAS_AVG);
}

static void do_baseline(canc_state_t *s)
{
    char out[80];
    float keepI = s->I, keepQ = s->Q;
    s->I = 0.0f; s->Q = 0.0f;        /* zero weight = no cancellation */
    base_adc = measure_point(s);
    base_valid = true;
    s->I = keepI; s->Q = keepQ;
    snprintf(out, sizeof(out), "baseline adc=%u (%.1f mV)\r\n",
             base_adc, (float)base_adc * 3300.0f / 4095.0f);
    console_print(out);
}

static void report_depth(canc_state_t *s, uint16_t a)
{
    char out[80];
    (void)s;
    if (base_valid) {
        float d = (float)((int32_t)base_adc - (int32_t)a) * DB_PER_COUNT;
        snprintf(out, sizeof(out), "adc=%u  depth=%.1f dB\r\n", a, d);
    } else {
        snprintf(out, sizeof(out), "adc=%u  (no baseline - press b)\r\n", a);
    }
    console_print(out);
}

/* Two-stage grid scan: coarse over the whole plane, then fine around the
 * best point. Finds the true achievable null independently of the search
 * algorithm - so if 'k' nulls deeply but 'a' does not, the problem is the
 * algorithm; if neither nulls, the problem is the RF. */
static void do_scan(canc_state_t *s, canc_mode_t *mode)
{
    char out[96];
    *mode = MODE_MANUAL;             /* algorithm must not fight the scan */

    if (!base_valid) do_baseline(s);

    float bestI = 0.0f, bestQ = 0.0f;
    uint16_t bestA = 0xFFFF;

    console_print("coarse scan (9x9)...\r\n");
    for (int qi = -4; qi <= 4; qi++) {
        for (int ii = -4; ii <= 4; ii++) {
            s->I = (float)ii * 0.25f;
            s->Q = (float)qi * 0.25f;
            uint16_t a = measure_point(s);
            if (a < bestA) { bestA = a; bestI = s->I; bestQ = s->Q; }
        }
    }
    snprintf(out, sizeof(out), "  coarse best I=%.3f Q=%.3f adc=%u\r\n",
             bestI, bestQ, bestA);
    console_print(out);

    console_print("fine scan (11x11)...\r\n");
    float cI = bestI, cQ = bestQ;
    for (int qi = -5; qi <= 5; qi++) {
        for (int ii = -5; ii <= 5; ii++) {
            s->I = cI + (float)ii * 0.05f;
            s->Q = cQ + (float)qi * 0.05f;
            if (s->I >  1.0f || s->I < -1.0f) continue;
            if (s->Q >  1.0f || s->Q < -1.0f) continue;
            uint16_t a = measure_point(s);
            if (a < bestA) { bestA = a; bestI = s->I; bestQ = s->Q; }
        }
    }

    console_print("ultra-fine scan (11x11)...\r\n");
    cI = bestI; cQ = bestQ;
    for (int qi = -5; qi <= 5; qi++) {
        for (int ii = -5; ii <= 5; ii++) {
            s->I = cI + (float)ii * 0.01f;
            s->Q = cQ + (float)qi * 0.01f;
            if (s->I >  1.0f || s->I < -1.0f) continue;
            if (s->Q >  1.0f || s->Q < -1.0f) continue;
            uint16_t a = measure_point(s);
            if (a < bestA) { bestA = a; bestI = s->I; bestQ = s->Q; }
        }
    }

    s->I = bestI; s->Q = bestQ;       /* park at the best point */
    snprintf(out, sizeof(out), "BEST I=%.3f Q=%.3f  ", bestI, bestQ);
    console_print(out);
    report_depth(s, bestA);
}

static void print_help(void)
{
    console_print("\r\n--- Co-Site Canceller ---\r\n");
    console_print("  m       manual mode\r\n");
    console_print("  a       auto mode (close the loop)\r\n");
    console_print("  i<val>  set I, -1..+1   e.g. i0.5\r\n");
    console_print("  q<val>  set Q, -1..+1\r\n");
    console_print("  v       raw ADC + depth\r\n");
    console_print("  z       zero I and Q\r\n");
    console_print("  b       capture baseline (I=Q=0)\r\n");
    console_print("  k       AUTO GRID SCAN -> finds the null\r\n");
    console_print("  g       dump convergence log + timing\r\n");
    console_print("  t       toggle telemetry\r\n");
    console_print("  s       status\r\n");
    console_print("> ");
}

void console_init(void)
{
    rxlen = 0; rxdone = false;
    telemetry = true;        // <-- FORCE TELEMETRY ON AT BOOT
    echo_head = 0; echo_tail = 0;
    console_print("\r\n[BOOT] Canceller ready. Telemetry streaming active.\r\n");
    print_help();
}
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

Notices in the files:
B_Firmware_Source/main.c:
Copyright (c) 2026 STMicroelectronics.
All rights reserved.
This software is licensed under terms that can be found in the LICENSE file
